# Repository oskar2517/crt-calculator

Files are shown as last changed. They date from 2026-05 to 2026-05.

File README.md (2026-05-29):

# CRT Calculator

Thie is the repository for my CRT calculator project. It contains the software for the microcontroller as well as production files for the PCB and case.

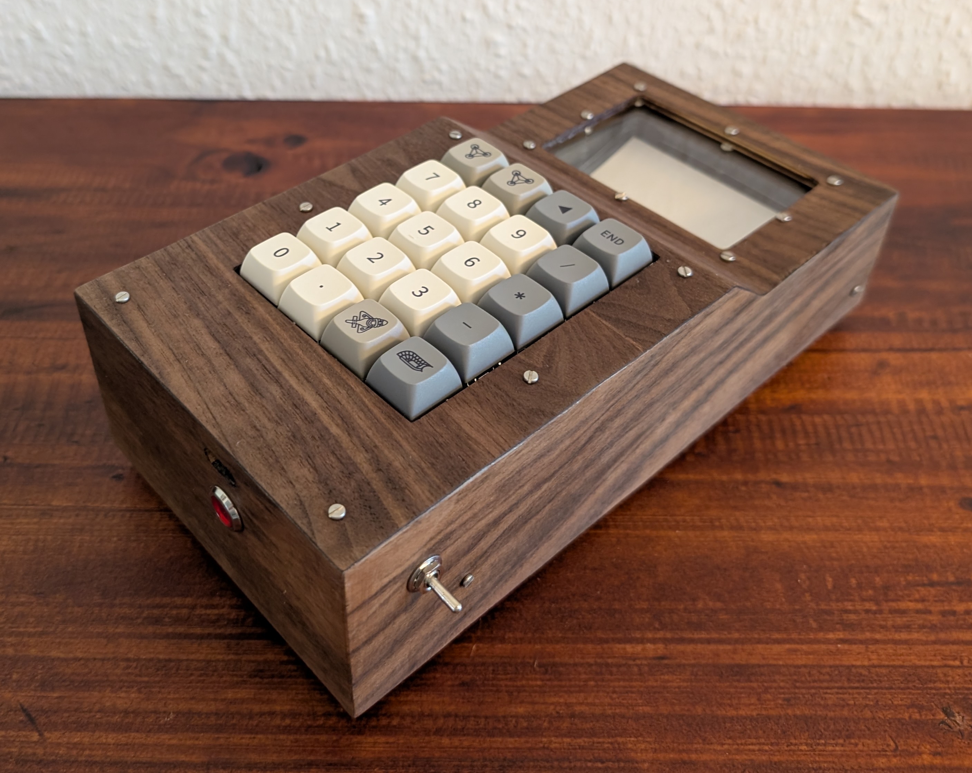
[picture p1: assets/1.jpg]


## Project Idea

I knew about the completely intgerated, self-scanning flat CRTs available from China for a long time but never had a clear vision of what I could do with one. Then one day, YouTube recommended me [this video](https://www.youtube.com/watch?v=pjzK-Lppa1c), which inspired me to make my own interpretation of a CRT calculator.

## Implementation

My project differs from the original in a few aspects. Firstly, I wanted my calculator to be battery-operated. It should be able to chargef through USB power delivery. Secondly, I wanted mine to have a case, which would contain all the necessary components. The finished calculator ended up weighing almost exactly one kilogram, so it's still not what one would generally consider pocketable :).

### PCB Design

I designed the PCB in EasyEDA. It contains all the components necessary including an ESP32 microcontroller, a charge controller, a 12V boost converter for the CRT and, of course, the keypad. I used a relatively old model of ESP32 because it still has a built-in DAC which I need for the composite video generation. All external components are attached using JST connectors.

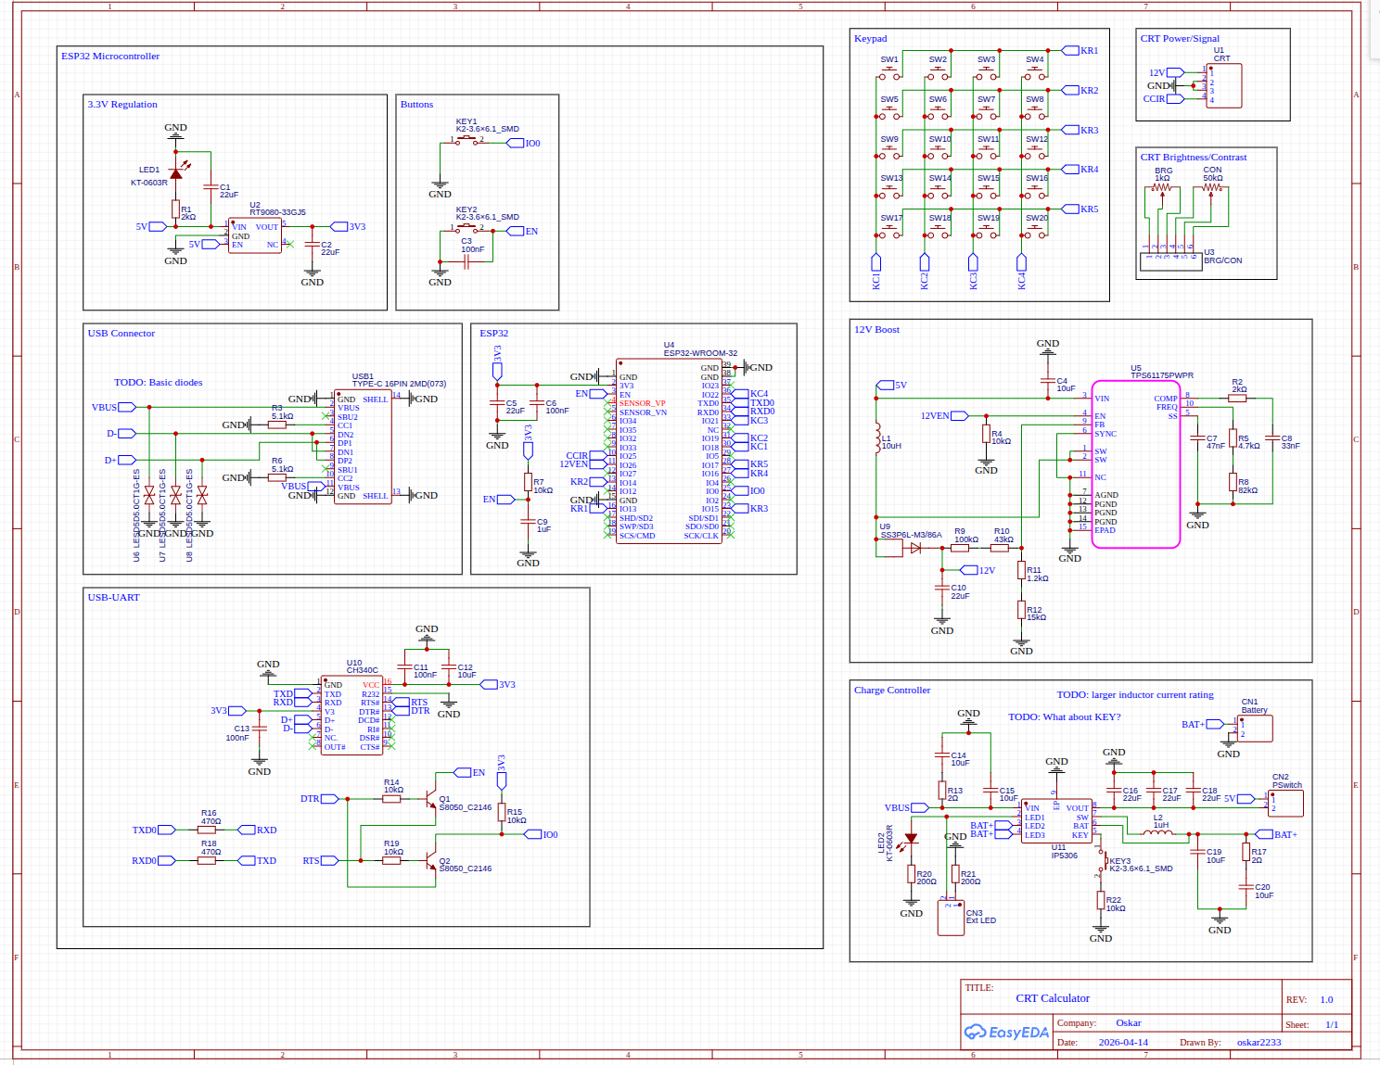
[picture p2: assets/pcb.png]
Schematic


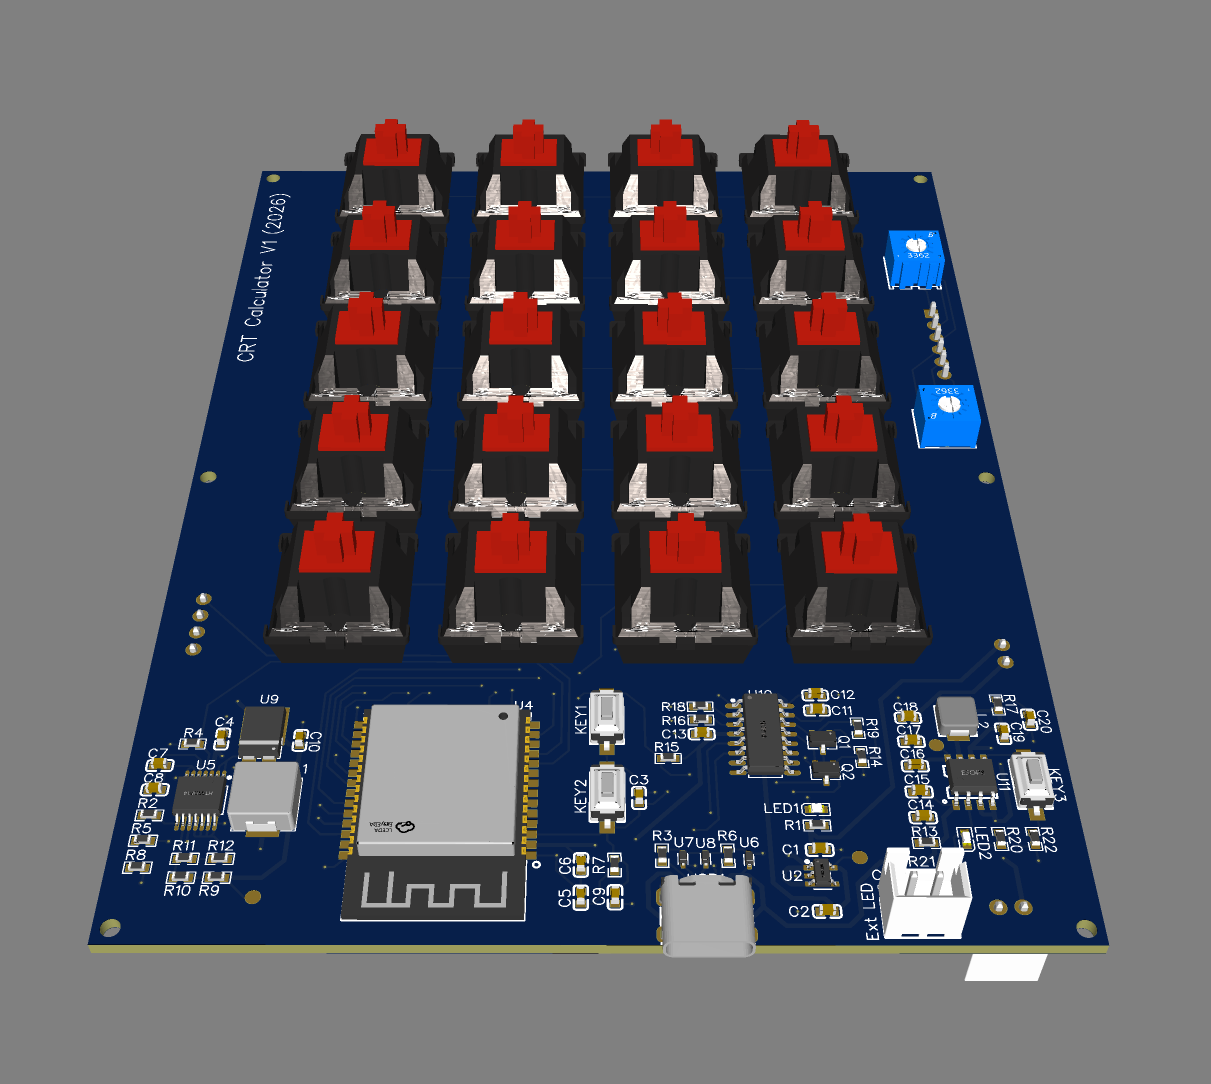
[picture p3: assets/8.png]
PCB


### Case Design

The case I designed in Onshape. It is intended to be laser-cut from 3mm plywood. I veneered it with walnut after assembly to give it a more uniform look.

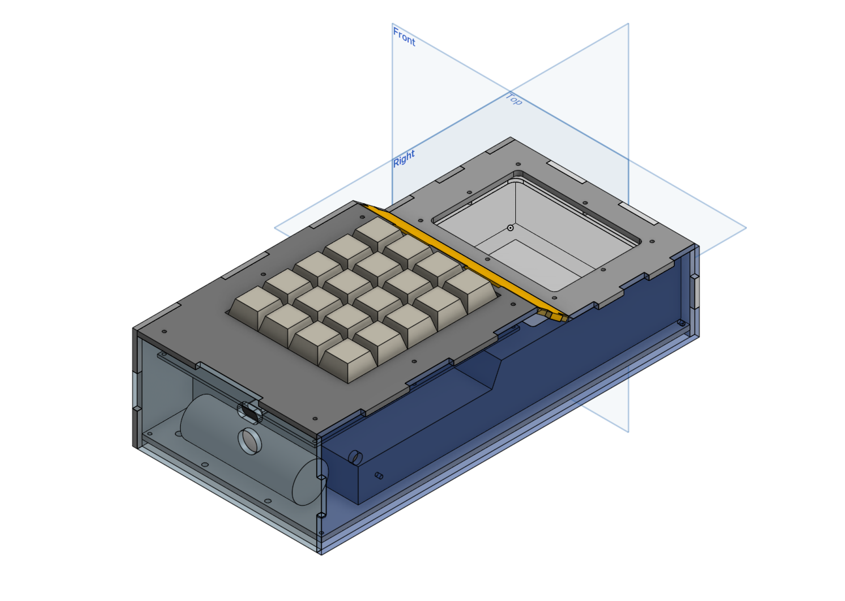
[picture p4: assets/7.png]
Onshape Design


Assembled

### Software

The software is written in C(++) and is currently still fairly basic. It is capable of parsing compound math expressions but still lacks any graphing abilities, which would lend themselves well to the CRT aspect. I also had some fun implementing a couple of additional modes, including the games Snake and Space Invaders and the obligatory Bad Apple.

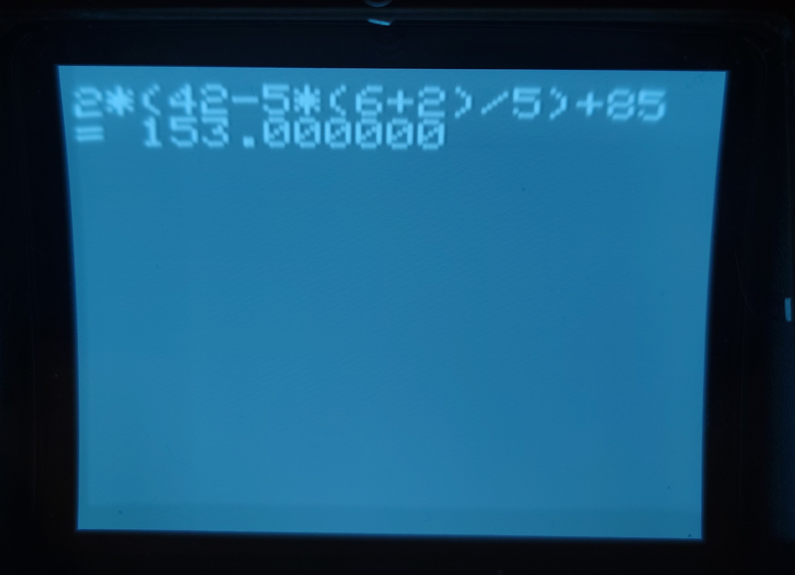
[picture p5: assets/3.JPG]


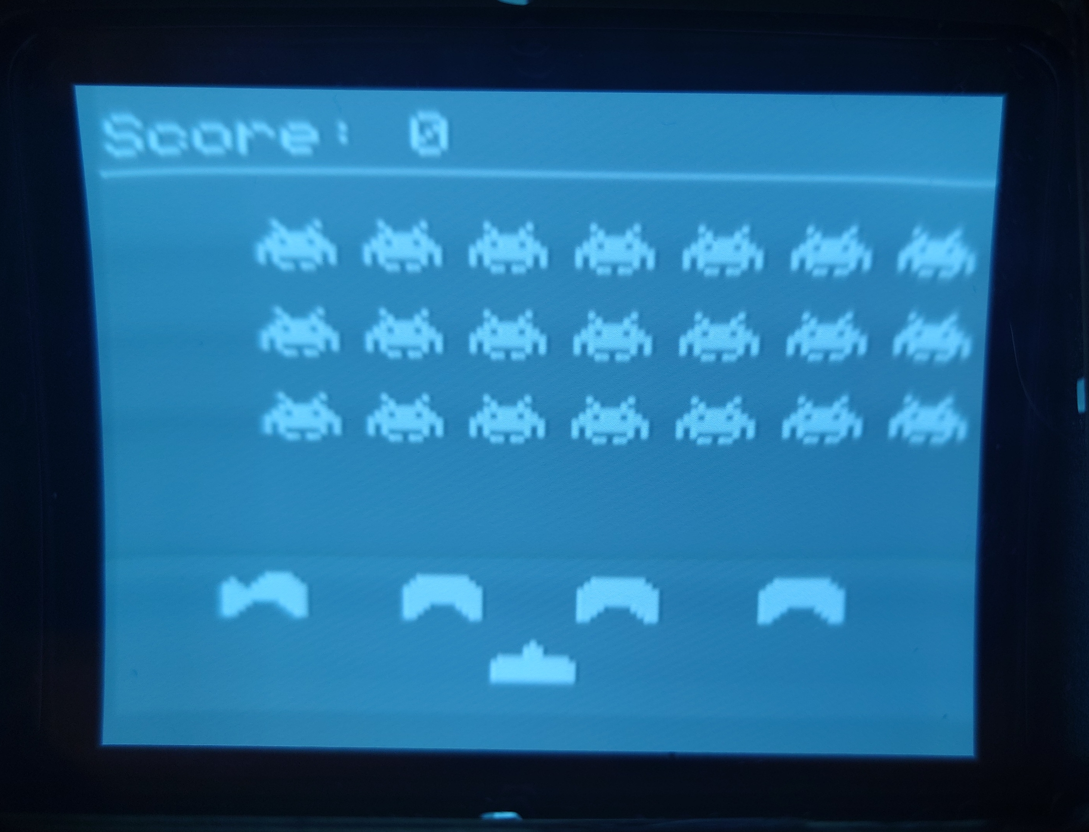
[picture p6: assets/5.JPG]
Space Invaders


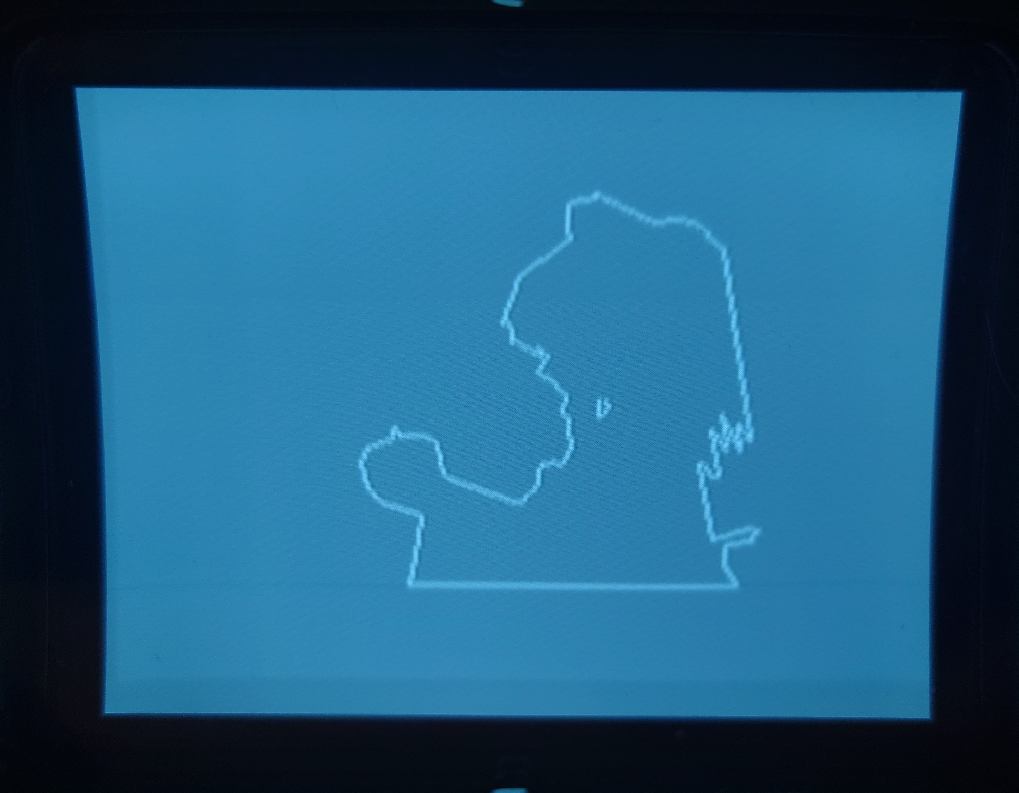
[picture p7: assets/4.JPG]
Bad Apple


### Videos

https://github.com/user-attachments/assets/d78290b7-812c-4778-8edb-842524321b57

https://github.com/user-attachments/assets/a9b024ef-ff24-45bf-a3b8-f66158780577

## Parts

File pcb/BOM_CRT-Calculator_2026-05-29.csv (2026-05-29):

ID | Name | Designator | Footprint | Quantity | Manufacturer Part | Manufacturer | Supplier | Supplier Part | Price
1 | CRT | U1 | CONN-TH_B4B-XH-A-LF-SN | 1 | B4B-XH-A(LF)(SN) | JST | LCSC | C144395 | 0.054
2 | BRG/CON | U3 | CONN-TH_6P-P2.50_B6B-XH-A-LF-SN | 1 | B6B-XH-A(LF)(SN) | JST | LCSC | C144397 | 0.088
3 | Battery | CN1 | CONN-TH_B2B-XH-A-LF-SN | 1 | B2B-XH-A(LF)(SN) | JST | LCSC | C158012 | 0.038
4 | PSwitch | CN2 | CONN-TH_B2B-XH-A-LF-SN | 1 | B2B-XH-A(LF)(SN) | JST | LCSC | C158012 | 0.038
5 | 1uF | C9 | C0603 | 1 | CL10A105KB8NNNC | SAMSUNG(三星) | LCSC | C15849 | 0.01
6 | 470Ω | R15 | R0603 | 1 | 0603WAF1002T5E | UNI-ROYAL(厚声) | LCSC | C25804 | 0.001
7 | 22uF | C1,C2,C5,C16,C17,C18 | C0603 | 6 | CL10A226MQ8NRNC | SAMSUNG(三星) | LCSC | C59461 | 0.013
8 | 100nF | C3,C6,C11,C13 | C0603 | 4 | CC0603KRX7R9BB104 | YAGEO(国巨) | LCSC | C14663 | 0.004
9 | 10uF | C4,C12,C14,C15,C19,C20 | C0603 | 6 | CL10A106MA8NRNC | SAMSUNG(三星) | LCSC | C96446 | 0.028
10 | 47nF | C7 | C0603 | 1 | CL10B473KB8NNNC | SAMSUNG(三星) | LCSC | C1622 | 0.006
11 | 33nF | C8 | C0603 | 1 | CL10B333KB8NNNC | SAMSUNG(三星) | LCSC | C21117 | 0.004
12 | 22uF | C10 | C0603 | 1 | CL10A226MO7JZNC | SAMSUNG(三星) | LCSC | C2762594 | 0.058
13 | 10kΩ | R7,R19,R22,R4,R14 | R0603 | 5 | 0603WAF1002T5E | UNI-ROYAL(厚声) | LCSC | C25804 | 0.001
14 | 470Ω | R16,R18 | R0603 | 2 | 0603WAF4700T5E | UNI-ROYAL(厚声) | LCSC | C23179 | 0.002
15 | 2Ω | R17,R13 | R0603 | 2 | 0603WAF200KT5E | UNI-ROYAL(厚声) | LCSC | C22977 | 0.002
16 | 200Ω | R20,R21 | R0603 | 2 | 0603WAF2000T5E | UNI-ROYAL(厚声) | LCSC | C8218 | 0.002
17 | KT-0603R | LED1,LED2 | LED0603-RD | 2 | KT-0603R | KENTO | LCSC | C2286 | 0.007
18 | S8050_C2146 | Q1,Q2 | SOT-23-3_L3.0-W1.7-P0.95-LS2.9-BR | 2 | S8050 J3Y(RANGE:200-350) | CJ(江苏长电/长晶) | LCSC | C2146 | 0.013
19 | 2kΩ | R1,R2 | R0603 | 2 | 0603WAF2001T5E | UNI-ROYAL(厚声) | LCSC | C22975 | 0.002
20 | RT9080-33GJ5 | U2 | TSOT-23-5_L2.9-W1.6-P0.95-LS2.8-BL | 1 | RT9080-33GJ5 | RICHTEK(立锜) | LCSC | C841192 | 0.118
21 | CH340C | U10 | SOP-16_L10.0-W3.9-P1.27-LS6.0-BL | 1 | CH340C | WCH(南京沁恒) | LCSC | C84681 | 0.585
22 | 5.1kΩ | R3,R6 | R0603 | 2 | 0603WAF5101T5E | UNI-ROYAL(厚声) | LCSC | C23186 | 0.002
23 | 82kΩ | R8 | R0603 | 1 | 0603WAF8202T5E | UNI-ROYAL(厚声) | LCSC | C23254 | 0.001
24 | 100kΩ | R9 | R0603 | 1 | 0603WAF1003T5E | UNI-ROYAL(厚声) | LCSC | C25803 | 0.002
25 | 43kΩ | R10 | R0603 | 1 | 0603WAF4302T5E | UNI-ROYAL(厚声) | LCSC | C23172 | 0.002
26 | 1.2kΩ | R11 | R0603 | 1 | 0603WAF1201T5E | UNI-ROYAL(厚声) | LCSC | C22765 | 0.001
27 | 15kΩ | R12 | R0603 | 1 | 0603WAF1502T5E | UNI-ROYAL(厚声) | LCSC | C22809 | 0.002
28 | 4.7kΩ | R5 | R0603 | 1 | 0603WAF4701T5E | UNI-ROYAL(厚声) | LCSC | C23162 | 0.001
29 | LESD5D5.0CT1G-ES | U6,U8,U7 | SOD-523_L1.2-W0.8-LS1.6-BI | 3 | LESD5D5.0CT1G-ES | ElecSuper(静芯微) | LCSC | C5199159 | 0.017
30 | SS3P6L-M3/86A | U9 | TO-277A_L6.1-W4.6-P2.13-LS6.5-TR | 1 | SS3P6L-M3/86A | VISHAY(威世) | LCSC | C968580 | 0.294
31 | IP5306 | U11 | ESOP-8_L4.9-W3.9-P1.27-LS6.0-BL-EP | 1 | IP5306 | INJOINIC(英集芯) | LCSC | C181692 | 0.282
32 | 1kΩ | BRG | RES-ADJ-TH_3362P | 1 | 3362P-1-102 | JIERR(捷而瑞) | LCSC | C48997915 | 0.135
33 | 50kΩ | CON | RES-ADJ-TH_3362P | 1 | 3362P-1-503 | JIERR(捷而瑞) | LCSC | C48997904 | 0.192
34 | K2-3.6×6.1_SMD | KEY1,KEY2,KEY3 | KEY-SMD_2P-L6.2-W3.6-LS8.0 | 3 | K2-1107ST-A4SW-06 |  | LCSC | C118141 | 0.074
35 | 10uH | L1 | IND-SMD_L7.1-W6.6 | 1 | YSPI0630A-100M | YJYCOIN(益嘉源) | LCSC | C497871 | 0.138
36 | 1uH | L2 | IND-SMD_L4.5-W4.1_GSSM0420 | 1 | MDA4020-1R0M | KOHERelec(科或) | LCSC | C2847468 | 0.897
37 | Cherry MX | SW1,SW2,SW3,SW4,SW5,SW6,SW7,SW8,SW9,SW10,SW11,SW12,SW13,SW14,SW15,SW16,SW17,SW18,SW19,SW20 | CHERRY MX | 20 | MX | CherryMX | Reichelt | MX1A-G1NW
38 | ESP32-WROOM-32 | U4 | WIFIM-SMD_ESP32-WROOM-32-N4 | 1 | ESP32-WROOM-32-N4 | ESPRESSIF(乐鑫) | LCSC | C82899 | 4.326
39 | TPS61175PWPR | U5 | HTSSOP-14_L5.0-W4.4-P0.65-LS6.4-BL-EP | 1 | TPS61175PWPR | TI(德州仪器) | LCSC | C43276 | 1.822
40 | TYPE-C 16PIN 2MD(073) | USB1 | USB-C-SMD_TYPE-C-6PIN-2MD-073 | 1 | TYPE-C 16PIN 2MD(073) | SHOU HAN(首韩) | LCSC | C2765186 | 0.074
41 | Ext LED | CN3 | CONN-TH_B2B-XH-A-LF-SN | 1 | B2B-XH-A(LF)(SN) | JST | LCSC | C158012 | 0.038

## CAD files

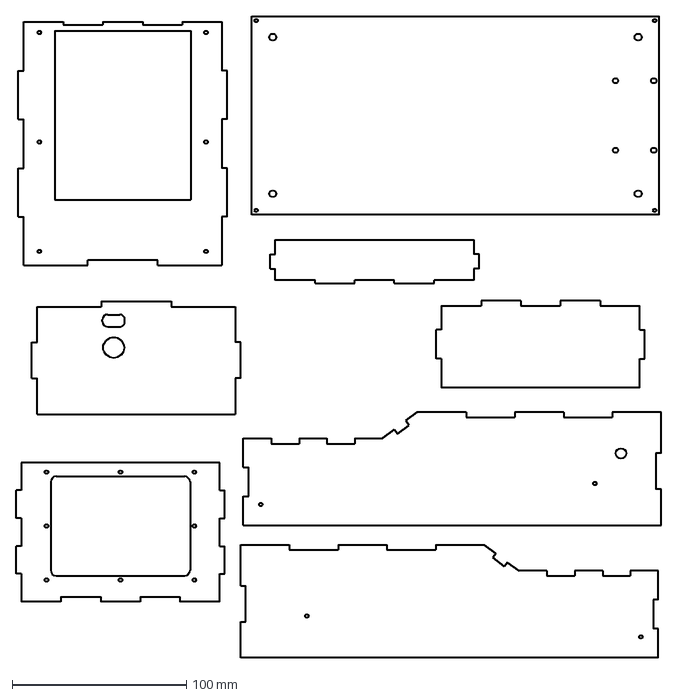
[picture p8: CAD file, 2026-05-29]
case/Case Drawing.dxf
370.7 x 368.6 mm

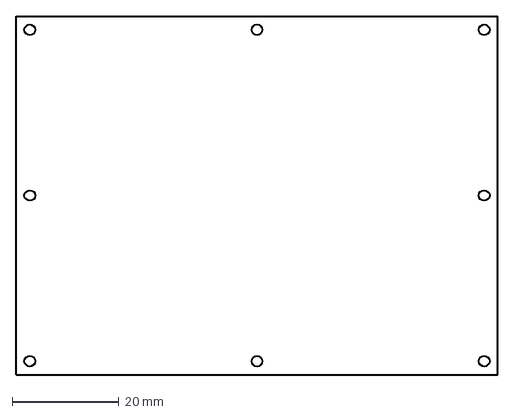
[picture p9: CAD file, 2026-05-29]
case/Screen Drawing.dxf
90.0 x 67.0 mm

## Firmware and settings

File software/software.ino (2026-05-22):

#include <Keypad.h>
#include <ESP_8_BIT_GFX.h>

#define MAX_OUTPUT_SIZE (21 * 2)
#define MAX_INPUT_SIZE (21 * 3)

#define MAX_TOKENS 250

#define KEYPAD_ROWS 5
#define KEYPAD_COLS 4

typedef enum {
  TOKEN_NUMBER,
  TOKEN_PLUS,
  TOKEN_MINUS,
  TOKEN_ASTERISK,
  TOKEN_SLASH,
  TOKEN_LEFT_PAREN,
  TOKEN_RIGHT_PAREN
} TokenType;

typedef struct {
  TokenType type;

  union {
    double number;
  };
} Token;

typedef struct {
  unsigned int token_count;
  Token *tokens;
} LexResult;

typedef struct {
  double value;
} ParseEvalResult;

char keypad_keys[KEYPAD_ROWS][KEYPAD_COLS] = {
  {'(',')','<','C'},
  {'7','8','9','/'},
  {'4','5','6','*'},
  {'1','2','3','-'},
  {'0','.','=','+'}
};

byte keypad_row_pins[KEYPAD_ROWS] = {13, 14, 15, 16, 17};
byte keypad_col_pins[KEYPAD_COLS] = {18, 19, 21, 22};

Keypad customKeypad = Keypad(makeKeymap(keypad_keys), keypad_row_pins, keypad_col_pins, KEYPAD_ROWS, KEYPAD_COLS);

ESP_8_BIT_GFX videoOut(false, 8 /* = RGB332 color */);

double lex_number(const char **input) {
  double value = 0.0;
  double divisor = 10.0;

  while (**input >= '0' && **input <= '9') {
    value = (value * 10) + (**input - '0');
    (*input)++;
  }

  if (**input == '.') {
    (*input)++;

    while (**input >= '0' && **input <= '9') {
      value += (**input - '0') / divisor;
      divisor *= 10.0;
      (*input)++;
    }
  }

  return value;
}

LexResult *lex(const char *input) {
  LexResult *result = (LexResult*) malloc(sizeof(*result));
  if (!result) return NULL;

  Token *tokens = (Token*) malloc(MAX_TOKENS * sizeof(*tokens));
  if (!tokens) {
    free(result);

    return NULL;
  }

  result->tokens = tokens;

  unsigned int token_pointer = 0;
  const char *str = input;

  while (*str) {
    if (token_pointer >= MAX_TOKENS) {
      free(tokens);
      free(result);

      return NULL;
    }

    Token *t = &tokens[token_pointer];

    if (*str >= '0' && *str <= '9') {
      t->type = TOKEN_NUMBER;
      t->number = lex_number(&str);

      token_pointer++;
      continue;
    }

    switch (*str) {
      case '+': t->type = TOKEN_PLUS; break;
      case '-': t->type = TOKEN_MINUS; break;
      case '*': t->type = TOKEN_ASTERISK; break;
      case '/': t->type = TOKEN_SLASH; break;
      case '(': t->type = TOKEN_LEFT_PAREN; break;
      case ')': t->type = TOKEN_RIGHT_PAREN; break;
      default:
        free(tokens);
        free(result);

        return NULL;
    }

    token_pointer++;
    str++;
  }

  result->token_count = token_pointer;

  return result;
}

int8_t precedence(Token *token) {
  switch (token->type) {
    case TOKEN_PLUS:
    case TOKEN_MINUS:
      return 1;

    case TOKEN_ASTERISK:
    case TOKEN_SLASH:
      return 2;
  }

  return -1;
}

bool parse_primary(LexResult *lex_result, unsigned int *position, double *value) {
  Token t = lex_result->tokens[*position];
  
  if (t.type == TOKEN_NUMBER) {
    (*position)++;
    *value = t.number;

    return true;
  }
  
  if (t.type == TOKEN_LEFT_PAREN) {
    (*position)++;
    ParseEvalResult *v = parse_eval_1(lex_result, position);
    if (v == NULL) {
      return false;
    }

    if (lex_result->tokens[*position].type != TOKEN_RIGHT_PAREN) {
      return false;
    }
    (*position)++;

    *value = v->value;
    free(v);

    return true;
  }

  if (t.type == TOKEN_MINUS) {
    (*position)++;

    double inner = 0;
    if (!parse_primary(lex_result, position, &inner)) {
      return false;
    }

    *value = -inner;
    return true;
  }

  return false;
}

double apply_operator(TokenType op, double left, double right) {
  switch (op) {
    case TOKEN_PLUS: return left + right;
    case TOKEN_MINUS: return left - right;
    case TOKEN_ASTERISK: return left * right;
    case TOKEN_SLASH: return left / right; // TODO: handle division by zero
  }

  // Unreachable
}

ParseEvalResult *parse_eval_2(LexResult *lex_result, unsigned int *position, double left, byte min_precedence) {
  while (*position < lex_result->token_count) {
    Token lookahead = lex_result->tokens[*position];

    if (precedence(&lookahead) < min_precedence) {
      break;
    }

    Token op = lookahead;
    (*position)++;

    double right = 0;
    if (!parse_primary(lex_result, position, &right)) {
      return NULL;
    }

    while (*position < lex_result->token_count) {
      lookahead = lex_result->tokens[*position];

      if (precedence(&lookahead) <= precedence(&op)) {
        break;
      }

      ParseEvalResult *right_result =
        parse_eval_2(lex_result, position, right, precedence(&op) + 1);

      if (right_result == NULL) {
        return NULL;
      }

      right = right_result->value;
      free(right_result);
    }

    left = apply_operator(op.type, left, right);
  }

  ParseEvalResult *r = (ParseEvalResult*) malloc(sizeof(*r));
  if (!r) return NULL;

  r->value = left;
  return r;
}

ParseEvalResult *parse_eval_1(LexResult *lex_result, unsigned int *position) {
  double left = 0;
  
  if (!parse_primary(lex_result, position, &left)) {
    return NULL;
  }

  return parse_eval_2(lex_result, position, left, 0);
}

ParseEvalResult *parse_eval(LexResult *lex_result) {
  unsigned int position = 0;

  ParseEvalResult *result = parse_eval_1(lex_result, &position);

  if (position != lex_result->token_count) {
    return NULL;
  }

  return result;
}

void setup(void) {
  Serial.begin(9600);
  videoOut.begin();

  // Enable 12V boost converter
  pinMode(26, OUTPUT);
  digitalWrite(26, HIGH);
}
  
void loop(void) {
  static char input[MAX_INPUT_SIZE + 1];
  static size_t input_pointer = 0;
  static char output[MAX_OUTPUT_SIZE];
  static bool has_output = false;
  static bool has_error = false; 
  static unsigned long last_cursor_blink = millis();
  static bool show_cursor = true;

  input[MAX_INPUT_SIZE] = '\0';

  videoOut.waitForFrame();

  videoOut.fillScreen(0);
  videoOut.setCursor(0, 20);
  videoOut.setTextSize(2);
  videoOut.setTextWrap(true);
  videoOut.setTextColor(0xFF);
  videoOut.print(input);

  
  if (!has_output) {
    if (show_cursor) {
      videoOut.print('_');
    }

    if (millis() - last_cursor_blink >= 500) {
      last_cursor_blink = millis();
      show_cursor = !show_cursor;
    }
  }

  if (has_output) {
    videoOut.print("\n= ");
    videoOut.print(output);
  }
 
  char read_key = customKeypad.getKey();

  if (!read_key) return;

  switch (read_key) {
    case 'C': {
      input_pointer = 0;
      has_output = false;
      has_error = false;
      memset(input, 0, sizeof(input));
      break;
    }

    case '=': {
      if (input_pointer == 0) return;

      LexResult *lex_result = lex(input);

      if (lex_result == NULL) {
        snprintf(output, MAX_OUTPUT_SIZE, "LEX ERROR");
        has_output = true;
        has_error = true;
        return;
      }

      ParseEvalResult *parse_eval_result = parse_eval(lex_result);

      free(lex_result->tokens);
      free(lex_result);

      if (parse_eval_result == NULL) {
        snprintf(output, MAX_OUTPUT_SIZE, "PARSE ERROR");
        has_output = true;
        has_error = true;
        return;
      }

      if (!isnormal(parse_eval_result->value)) {
        snprintf(output, MAX_OUTPUT_SIZE, "MATH ERROR");
        has_output = true;
        has_error = true;
        return;
      }

      memset(output, 0, sizeof(output));
      snprintf(output, MAX_OUTPUT_SIZE, "%f", parse_eval_result->value);
      has_output = true;

      free(parse_eval_result);

      break;
    }

    case '<': {
      if (has_output || input_pointer <= 0) return;

      // Do not blink while typing
      show_cursor = true;
      last_cursor_blink = millis();

      input_pointer--;
      input[input_pointer] = '\0';

      break;
    }

    default: {
      if (has_error) return;

      if (has_output) {
        has_output = false;
        memset(input, 0, sizeof(input));
        memcpy(input, output, sizeof(input));
        input_pointer = strlen(output);
      }

      if (input_pointer >= MAX_INPUT_SIZE) return;

      // Do not blink while typing
      show_cursor = true;
      last_cursor_blink = millis();

      input[input_pointer++] = read_key;
      input[input_pointer] = '\0';
    }
  }
}

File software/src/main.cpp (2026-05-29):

#include <Arduino.h>
#include <LittleFS.h>
#include <stdint.h>

#include "bad_apple.h"
#include "calculator.h"
#include "invaders.h"
#include "keypad.h"
#include "snake.h"
#include "video.h"

#define MODE_SWITCH_WINDOW_MS UINT32_C(350)

typedef struct {
    void (*enter)();
    void (*exit)();
    void (*render)();
    void (*handle_key)(char read_key);
} AppMode;

static uint8_t current_mode_index = 0;
static uint32_t last_clear_press = 0;

static AppMode app_modes[] = {
    {calculator_enter, calculator_exit, calculator_render,
     calculator_handle_key},
    {snake_enter, snake_exit, snake_render, snake_handle_key},
    {invaders_enter, invaders_exit, invaders_render, invaders_handle_key},
    {bad_apple_enter, bad_apple_exit, bad_apple_render, bad_apple_handle_key},
};

static uint8_t app_mode_count() {
    return sizeof(app_modes) / sizeof(app_modes[0]);
}

static AppMode* current_mode() { return &app_modes[current_mode_index]; }

static void switch_mode(uint8_t mode_index) {
    current_mode()->exit();
    current_mode_index = mode_index % app_mode_count();
    current_mode()->enter();
}

static void switch_to_next_mode() { switch_mode(current_mode_index + 1); }

static bool handle_mode_shortcut(char read_key) {
    if (read_key != 'C') {
        last_clear_press = 0;
        return false;
    }

    uint32_t now = millis();

    if (last_clear_press != 0 &&
        now - last_clear_press <= MODE_SWITCH_WINDOW_MS) {
        last_clear_press = 0;
        switch_to_next_mode();
        return true;
    }

    last_clear_press = now;
    return false;
}

void setup() {
    // Enable 12V boost converter
    pinMode(26, OUTPUT);
    digitalWrite(26, HIGH);

    Serial.begin(9600);
    video_out.begin();
    if (!LittleFS.begin(true)) {
        Serial.println("An Error has occurred while mounting LittleFS");
        return;
    }
    current_mode()->enter();
}

void loop() {
    AppMode* mode = current_mode();

    mode->render();

    char read_key = keypad.getKey();

    if (!read_key) return;

    if (handle_mode_shortcut(read_key)) return;

    mode->handle_key(read_key);
}

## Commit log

2026-05-22 disallow typing in error state
    [software.ino]
2026-05-29 Space invaders (#2)
    * start work on space invaders
    * get basic movement + shooting working
    * further work
    * fix memory leak
    * fix explosion bug
    * fix stale timer issues
    * make internal functions static
    * cleanup code
    * set calculator as default app
    * implement barricades
    * unify entity drawing
    * create constant for barricade y
    * improve balancing
    * revert default app to calculator
    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
    [main.cpp]
2026-05-29 add basic project structure
    [BOM_CRT-Calculator_2026-05-29.csv, Case Drawing.dxf, Screen Drawing.dxf]
2026-06-03 fix switching modes from invaders not working properly
